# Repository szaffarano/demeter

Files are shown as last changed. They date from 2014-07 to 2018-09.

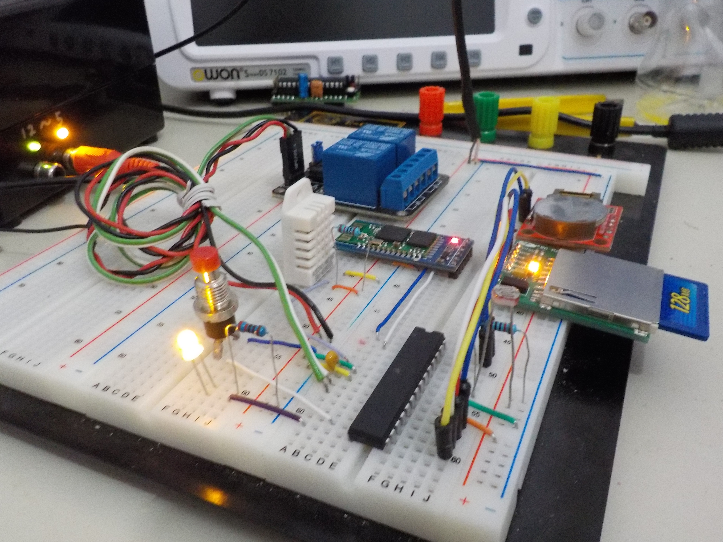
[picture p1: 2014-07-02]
photos/prototipo.JPG

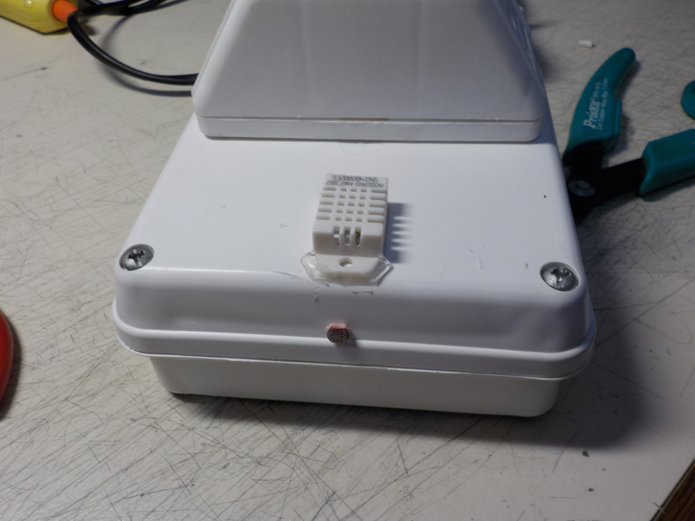
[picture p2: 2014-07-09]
photos/terminado2.JPG

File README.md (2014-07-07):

## Demeter

Controlador de riego que incorpora algunas mejoras con respecto a su predecesor baudino relacionadas con el manejo remoto y ampliación de sensores que maneja.

Está implementado en un microcontrolador AVR ATMega328 **sin bootloeader ni librerías Arduino**.

Versión preliminar con una implementación parcial del protocolo modbus.

### Roadmap

- ~~Terminar de mapear registros modbus a sensores, parámetros y comandos del controlador.~~
- Implementar servicio rest para interactuar remotamente.
- Realizar prueba de concepto para usar NRF24L01+ en lugar del módulo bluetooth.
- ~~Documentar esquemáticos en kicad~~.
- Armar una webapp para administrar el controlador.
- Incorporar interrupción watchdog para preveer posibles fallos.
- Implementar los relays usando triacs+opto.
- Agregar sensor de humedad de tierra.
- Desdoblar los controles para riego tradicional (tierra) e hidropónico en forma independiente.
- Optimizar lógica en los mapeos para ahorrarse algunos ciclos de cpu y memoria.
- Agregar en el cliente python funciones de alto nivel (ej get_date que lea grupo de registros de la fecha en vez de llamar a read_holding_registers).
- ~~Refactorizar mapeo de registros modbus para optimizar bits y que no quede todo en uint16_t.~~ (DUPLICADO).
- Optimizar algoritmo en los callbacks modbus.
- Generar tickets github para no mantener un archivo de pendientes...

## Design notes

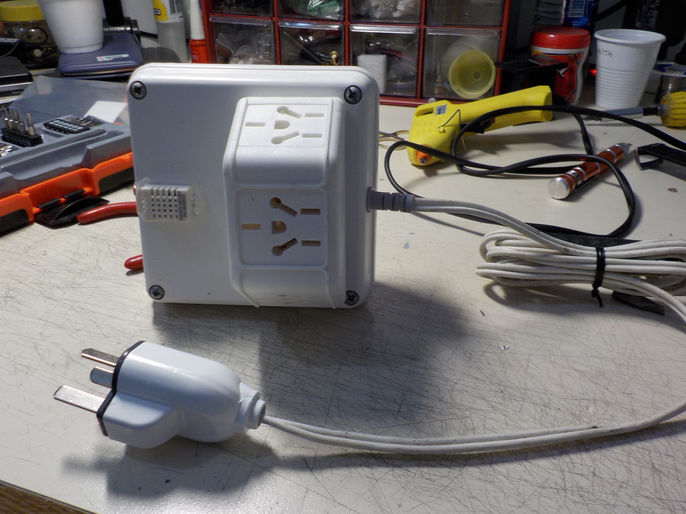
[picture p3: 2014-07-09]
photos/terminado1.JPG

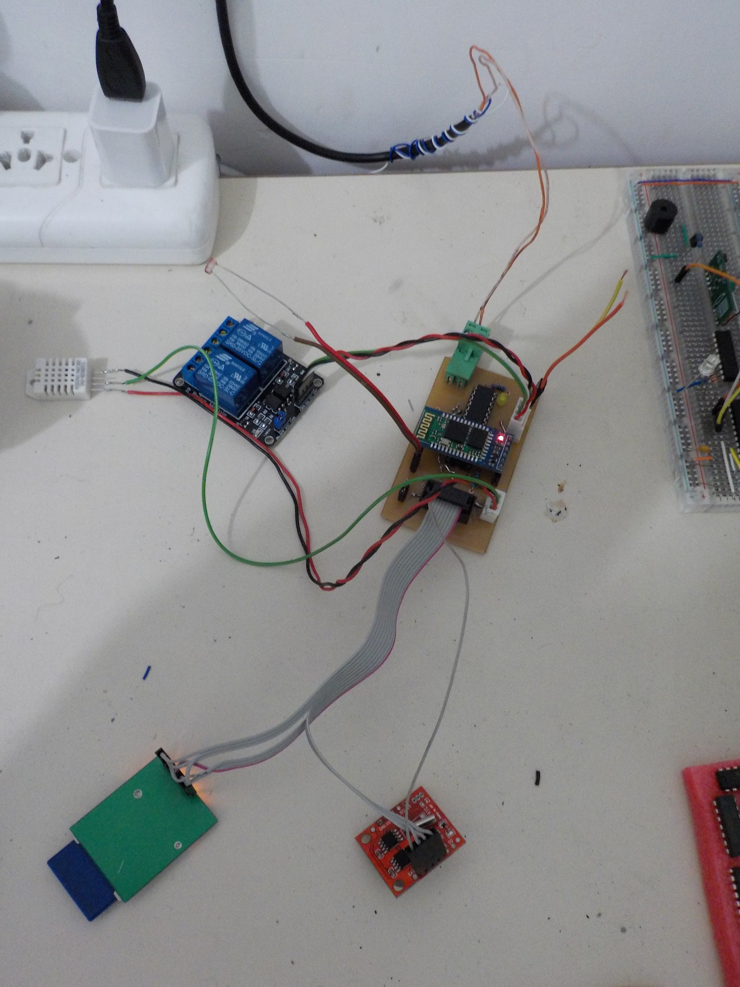
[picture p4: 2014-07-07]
photos/pcb_comienzo.JPG

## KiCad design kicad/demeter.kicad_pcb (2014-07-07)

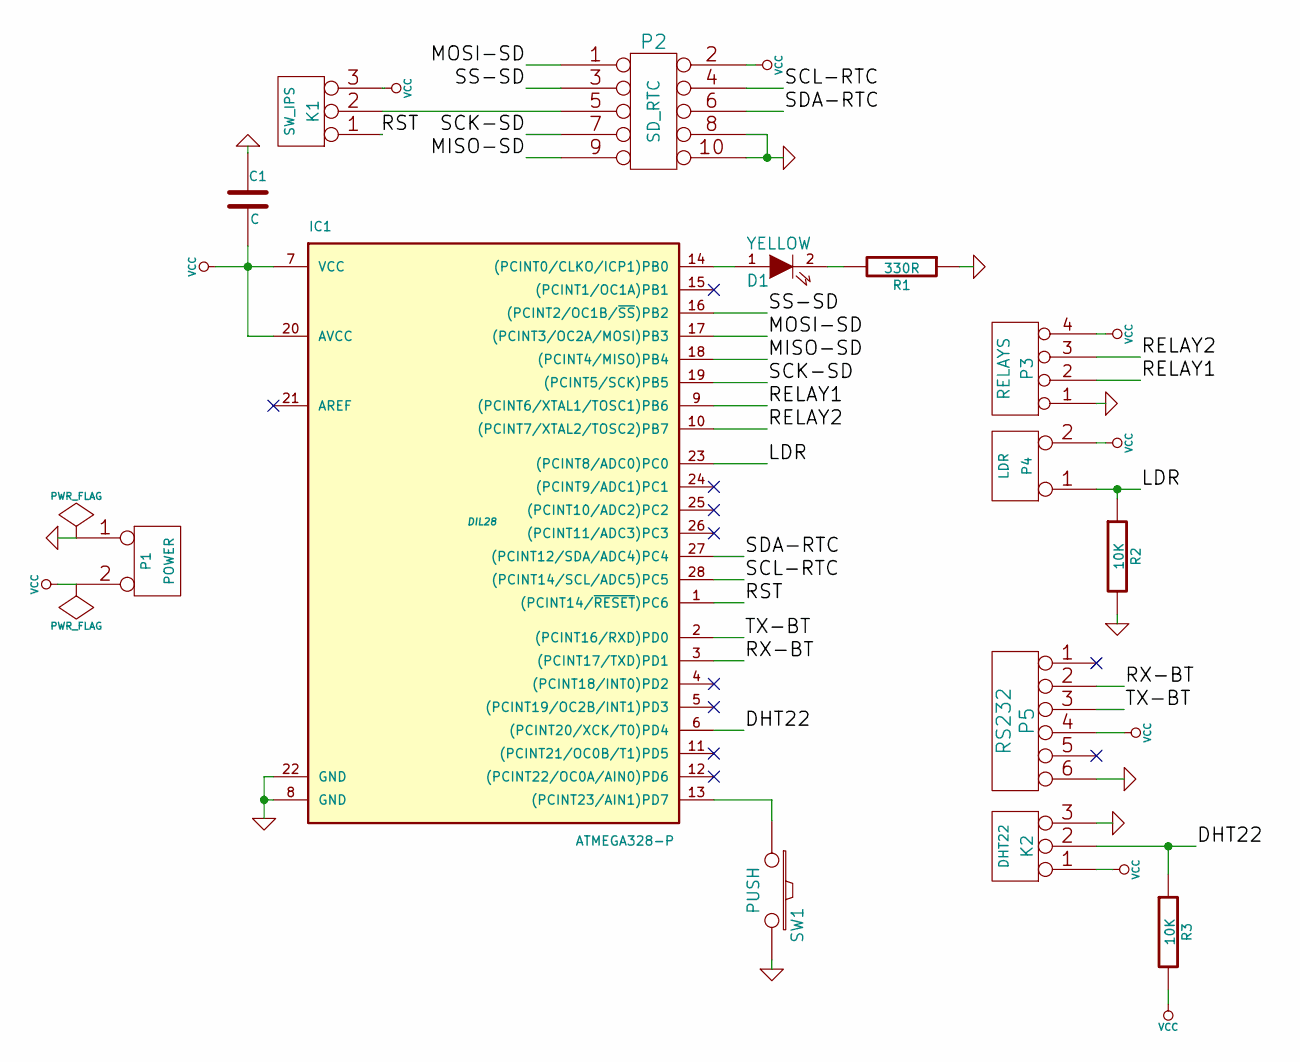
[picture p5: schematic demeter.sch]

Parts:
C1: C
D1: YELLOW
IC1: ATMEGA328-P; DIL28
K1: SW_IPS
K2: DHT22
P1: POWER
P2: SD_RTC
P3: RELAYS
P4: LDR
P5: RS232
R1: 330R
R2, R3: 10K
SW1: PUSH

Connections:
/DHT22: IC1.6 ((PCINT20/XCK/T0)PD4), K2.2 (PM), R3.1
/LDR: IC1.23 ((PCINT8/ADC0)PC0), P4.1, R2.1
/MISO-SD: IC1.18 ((PCINT4/MISO)PB4), P2.9
/MOSI-SD: IC1.17 ((PCINT3/OC2A/MOSI)PB3), P2.1
/RELAY1: IC1.9 ((PCINT6/XTAL1/TOSC1)PB6), P3.2
/RELAY2: IC1.10 ((PCINT7/XTAL2/TOSC2)PB7), P3.3
/RST: IC1.1 ((PCINT14/~RESET~)PC6), K1.1
/RX-BT: IC1.3 ((PCINT17/TXD)PD1), P5.2
/SCK-SD: IC1.19 ((PCINT5/SCK)PB5), P2.7
/SCL-RTC: IC1.28 ((PCINT14/SCL/ADC5)PC5), P2.4
/SDA-RTC: IC1.27 ((PCINT12/SDA/ADC4)PC4), P2.6
/SS-SD: IC1.16 ((PCINT2/OC1B/~SS~)PB2), P2.3
/TX-BT: IC1.2 ((PCINT16/RXD)PD0), P5.3
GND: C1.1, IC1.8 (GND), IC1.22 (GND), K2.3, P1.1, P2.8, P2.10, P3.1, P5.6, R1.1, R2.2, SW1.2
unnamed: D1.1 (A), IC1.14 ((PCINT0/CLKO/ICP1)PB0)
unnamed: D1.2 (K), R1.2
unnamed: IC1.13 ((PCINT23/AIN1)PD7), SW1.1
unnamed: K1.2 (PM), P2.5
VCC: C1.2, IC1.7 (VCC), IC1.20 (AVCC), K1.3, K2.1, P1.2 (PM), P2.2, P3.4, P4.2 (PM), P5.4, R3.2

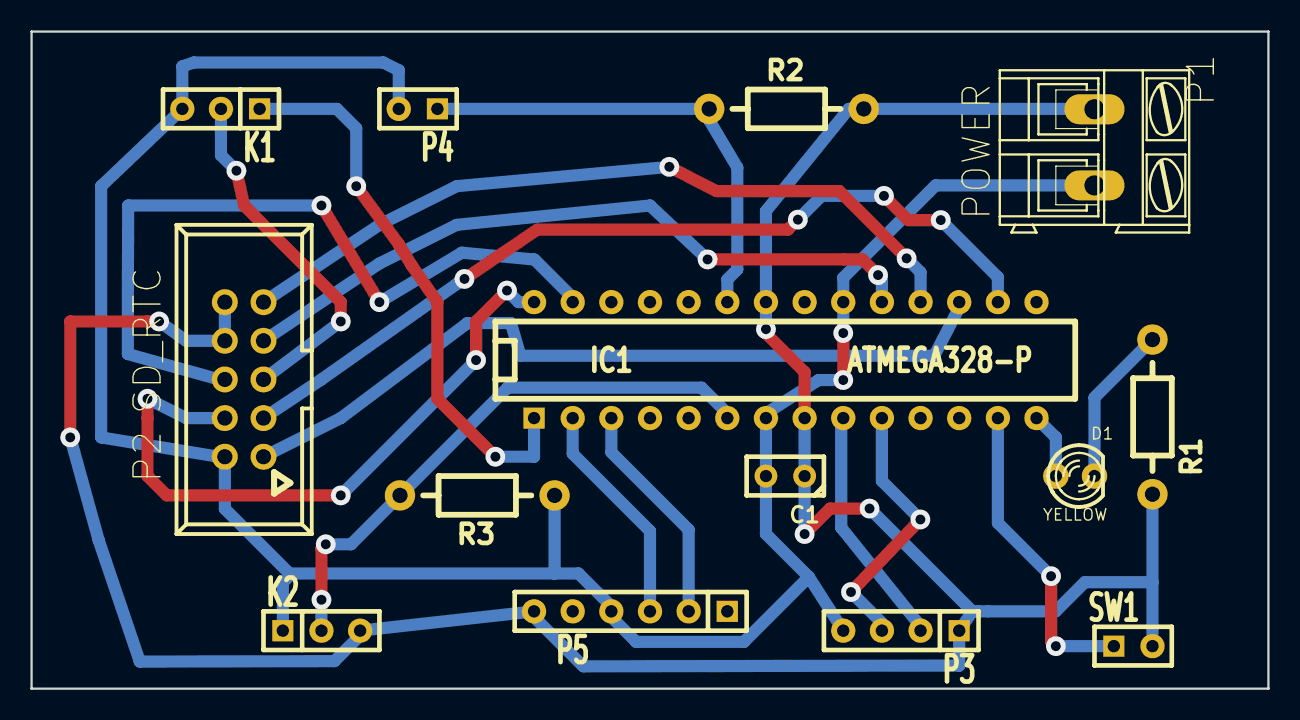
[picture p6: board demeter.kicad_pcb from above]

Board: 2 copper layers, 81.3 x 43.2 mm, 14 parts (0 on the bottom side), 19 nets.

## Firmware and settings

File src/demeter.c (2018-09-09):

/*
 * main.c
 *
 *  Created on: 07/06/2014
 *      Author: sebas
 */

#include <mb.h>
#include <mbport.h>

#include <avr/io.h>
#include <util/delay.h>
#include <avr/interrupt.h>
#include <string.h>
#include <stdlib.h>
#include <ctype.h>

#include <demeter.h>
#include <adc.h>
#include <ports.h>
#include <timer.h>

#include <config.h>

#include <DHT22.h>

#include <stdio.h>

#include <ff.h>

#include <i2c.h>
#include <rtc.h>
#include <rtc_ds1307.h>

#define DATETIME_SIZE	(sizeof(datetime_t) / 2)
#define EVENTS_SIZE		((sizeof(event_t) * MAX_EVENTS) / 2)
#define LOGEVENT_SIZE	(sizeof(uint16_t) / 2)
#define STATE_SIZE		(sizeof(state_t) / 2)
#define NUMBER_OF_COILS	2

FATFS fs;
FIL log_file;
rtc_device_t *rtc = &rtc_ds1307;

state_t state;
datetime_t datetime;
uint8_t relays; /* estado de los relays, lo manejo con bitwise operations */

// "yyyymmdd.log"
static char log_filename[13] = "nn.log";
static char last_logfilename[13] = "empty.log";

volatile unsigned int ticks = 0;

static void timer0_callback(void);
static inline long get_seconds(instant_t t);
static inline void update_state(void);
static inline void update_log_filename(void);

/**
 * MCU: Atmega328
 * Fuses: Oscilador interno a 8 Mhz (sin dividir por 8)
 * 		-U lfuse:w:0xe2:m -U hfuse:w:0xd1:m -U efuse:w:0x07:m
 */
int main(void) {
	adc_init();

	timer0_init(timer0_callback);

	i2c_init();

	rtc_init(rtc);
	rtc_sqw_rate(rtc, 1);
	rtc_sqw_enable(rtc);
	rtc_clock_start(rtc);

	eMBInit(MB_RTU, 0x03, 0, 9600, MB_PAR_NONE);
	eMBSetSlaveID(0x3, TRUE, (UCHAR*) "demeter", 8);
	eMBEnable();

	blinkenlight(5, 100);

	parameters_init();

	ports_init();

	f_mount(&fs, "", 0);
	update_log_filename();

	while (1) {
		eMBPoll();
		update_state();

		_delay_ms(100);
	}

	return (0);
}

static inline void update_state(void) {
	DHT22_DATA_t sensor_values;
	rtc_datetime_24h_t current_dt;
	readDHT22(&sensor_values);
	rtc_read(rtc, &current_dt);

	event_t* events = get_events();
	long start_secs;
	long current_secs;
	uint8_t i = 0;
	uint8_t flag = 0;

	state.temperature = sensor_values.raw_temperature;
	state.humidity = sensor_values.raw_humidity;
	state.light = adc_read(PHOTORESISTOR);

	datetime = (datetime_t ) { .year = current_dt.year, .month =
					current_dt.month, .date = current_dt.date, .hour =
					current_dt.hour, .minute = current_dt.minute, .second =
					current_dt.second };

	current_secs = get_seconds((instant_t ) {
					datetime.hour,
					datetime.minute,
					datetime.second });

	// recorro eventos para ver si tengo que activar relays
	for (i = 0; i < MAX_EVENTS; i++) {
		if (events[i].enabled) {
			start_secs = get_seconds(events[i].start);
			if (start_secs < current_secs
					&& (start_secs + events[i].duration) > current_secs) {
				flag |= (1 << events[i].target); /* activar el evento */
			}
		}
	}

	// si activaron coil, estamos dentro de un evento o presionaron pulsador
	for (uint8_t i = 0; i < NUMBER_OF_COILS; i++) {
		if (relays & (1 << i) || (flag & (1 << i)) || is_pushed()) {
			enable_relay(i);
		} else {
			disable_relay(i);
		}
	}

	if (ticks >= get_log_interval()) {
		update_log_filename(); /* si cambio el dia y hay que hacer roll del archivo */

		//yyyyMMddhhmmss	light	humidity	temperature
		f_printf(&log_file, "%04d%02d%02d%02d%02d%02d\t%d\t%d\t%d\t%d\t%d\n",
				datetime.year, datetime.month, datetime.date, datetime.hour,
				datetime.minute, datetime.second, state.light, state.humidity,
				state.temperature, is_relay_enabled(0), is_relay_enabled(1));
		f_sync(&log_file);
		ticks = 0;
	}
}

void timer0_callback() {
	ticks++;
	LED_PORT ^= _BV(LED);
}

/* Callbacks Modbus */

eMBErrorCode eMBRegInputCB(UCHAR * pucRegBuffer, USHORT usAddress,
		USHORT usNRegs) {

	if ((usAddress + usNRegs - 1) > STATE_SIZE) {
		return MB_ENOREG;
	}
	int16_t* raw_state = (int16_t*) &state;

	raw_state += usAddress - 1;
	while (usNRegs > 0) {
		*pucRegBuffer++ = (*raw_state >> 8);
		*pucRegBuffer++ = (*raw_state & 0xFF);
		usNRegs--;
		raw_state++;
	}

	return MB_ENOERR;
}

/**
 * Holding registers (empieza en 1):
 * 	LOG_INTERVAL + DATETIME + EVENTS
 */
eMBErrorCode eMBRegHoldingCB(UCHAR * buffer, USHORT address, USHORT regs,
		eMBRegisterMode mode) {

	// indice para saber por qué grupo de registros voy avanzando
	uint16_t idx = address;

	// hago operaciones de bit en una variable, para no usar dos
	// es para indicar si debo actualizar el grupo de registros
	// de eventos y/o datetime.
	uint8_t flag = 0;

	// grupo de registros correspondiente a datetime
	uint16_t* dt = (uint16_t*) &datetime;

	// grupo de registros correspondiente a los eventos.
	uint16_t* events = (uint16_t*) get_events();

	if ((address + regs - 1) > (EVENTS_SIZE + LOGEVENT_SIZE + DATETIME_SIZE)) {
		return MB_ENOREG;
	}

	// si me piden algo que va mas allá de logevent (primer registro)
	// avanzo el siguiente grupo, datetime
	if (address > LOGEVENT_SIZE) {
		dt += address - LOGEVENT_SIZE - 1;
	}

	// si me piden algo que va mas allá del segundo registro (datetime)
	// avanzo el tercer grupo, events hasta donde haga falta.
	if (address > (LOGEVENT_SIZE + DATETIME_SIZE)) {
		events += address - LOGEVENT_SIZE - DATETIME_SIZE - 1;
	}

	// operación de lectura
	if (mode == MB_REG_READ) {
		for (; idx < regs + address; idx++) {
			if (idx > 0 && idx <= LOGEVENT_SIZE) {
				uint16_t log_interval = get_log_interval();
				*buffer++ = (log_interval >> 8);
				*buffer++ = (log_interval & 0xFF);
			} else if (idx > LOGEVENT_SIZE
					&& idx <= (LOGEVENT_SIZE + DATETIME_SIZE)) {
				*buffer++ = (*dt >> 8);
				*buffer++ = (*dt & 0xFF);
				dt++;
			} else {
				*buffer++ = (*events >> 8);
				*buffer++ = (*events & 0xFF);
				events++;
			}
		}
		// operación de escritura
	} else {
		for (; idx < regs + address; idx++) {
			if (idx > 0 && idx <= LOGEVENT_SIZE) {
				uint16_t log_interval = (*buffer++ << 8);
				log_interval |= (*buffer++ & 0xFF);
				set_log_interval(log_interval);
			} else if (idx > LOGEVENT_SIZE
					&& idx <= (LOGEVENT_SIZE + DATETIME_SIZE)) {
				*dt = (*buffer++ << 8);
				*dt |= (*buffer++ & 0xFF);
				dt++;
				flag |= (1 << 1); /* se modifica algun campo de la fecha, marco flag */
			} else {
				*events = (*buffer++ << 8);
				*events |= (*buffer++ & 0xFF);
				events++;
				flag |= (1 << 2); /* se modifica algún evento, marco flag */
			}
		}

		if ((flag & (1 << 1))) {
			rtc_datetime_24h_t newdate;
			newdate.year = datetime.year;
			newdate.month = datetime.month;
			newdate.date = datetime.date;
			newdate.hour = datetime.hour;
			newdate.minute = datetime.minute;
			newdate.second = datetime.second;
			rtc_write(rtc, &newdate);
		}

		if ((flag & (1 << 2))) {
			set_events(get_events());
		}
	}

	return MB_ENOERR;
}

eMBErrorCode eMBRegCoilsCB(UCHAR * pucRegBuffer, USHORT usAddress,
		USHORT usNCoils, eMBRegisterMode eMode) {
	if (usAddress + usNCoils - 1 > NUMBER_OF_COILS) {
		return MB_ENOREG;
	}
	usAddress--; /* empiezo en cero. */
	if (eMode == MB_REG_READ) {
		while (usNCoils > 0) {
			if (relays & (1 << usAddress)) {
				*pucRegBuffer |= (1 << usAddress);
			}
			usNCoils--;
			usAddress++;
		}
	} else {
		*pucRegBuffer <<= usAddress;
		while (usNCoils > 0) {
			if ((*pucRegBuffer & (1 << usAddress))) {
				relays |= (1 << usAddress);
			} else {
				relays &= ~(1 << usAddress);
			}
			usNCoils--;
			usAddress++;
		}
	}
	return MB_ENOERR;
}

eMBErrorCode eMBRegDiscreteCB(UCHAR * pucRegBuffer, USHORT usAddress,
		USHORT usNDiscrete) {
	return MB_ENOREG;
}

/**
 * Función usada para setearle la fecha a los archivos.
 */
DWORD get_fattime(void) {
	rtc_datetime_24h_t current_dt;
	rtc_read(rtc, &current_dt);
	return ((DWORD) (current_dt.year - 1980) << 25) /* Year */
	| ((DWORD) current_dt.month << 21) /* Month */
	| ((DWORD) current_dt.date << 16) /* Mday */
	| ((DWORD) current_dt.hour << 11) /* Hour */
	| ((DWORD) current_dt.minute << 5) /* Min */
	| ((DWORD) current_dt.second >> 1); /* Sec */
}

/**
 * Convierte un instant_t a segundos.  Esos segundos representan el tiempo
 * transcurrido desde las 0 hs hasta el momento del instante
 * propiamente dicho.
 */
static inline long get_seconds(instant_t t) {
	return (t.hour * 60 * 60) + (t.minute * 60) + t.second;
}

static inline void update_log_filename(void) {
	rtc_datetime_24h_t dt;
	rtc_read(rtc, &dt);
	sprintf(log_filename, "%04d%02d%02d.log", dt.year, dt.month, dt.date);
	if (strcmp(log_filename, last_logfilename) != 0) {
		f_close(&log_file);
		if (f_open(&log_file, log_filename, FA_OPEN_ALWAYS | FA_WRITE)
				== FR_OK) {
			if (f_lseek(&log_file, f_size(&log_file)) == FR_OK) {
				f_sync(&log_file);
			}
		}
		strcpy(last_logfilename, log_filename);
	}
}

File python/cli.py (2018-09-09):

#!/usr/bin/env python
# -*- coding: utf-8 -*-

import logging
import argparse

from utils import Console, DemeterClient
from pymodbus.pdu import ExceptionResponse
from pymodbus.register_write_message import WriteMultipleRegistersResponse
from pymodbus.register_read_message import ReadRegistersResponseBase
from pymodbus.bit_read_message import ReadBitsResponseBase
from pymodbus.bit_write_message import WriteMultipleCoilsResponse

LOG_FILENAME = '/tmp/modbus-cli.log'
HISTORY_FILENAME = '/tmp/.modbus_history'

MODBUS_CLIENT_ID = 0x03

# Configuración del log
logging.basicConfig(
    filename=LOG_FILENAME,
    level=logging.DEBUG,
)

# Opciones para el autocompletado
autocompletions = {
    'read_coils': [],
    'read_discrete_inputs': [],
    'read_holding_registers': [],
    'read_input_registers': [],
    'write_coils': [],
    'write_registers': [],

    'get_datetime': [],
    'set_datetime': [],
    'get_loginterval': [],
    'set_loginterval': [],
    'read_event': [],
    'write_event': [],
    'read_events': [],
    'disable_event': [],
    'enable_event': [],
    'disable_relay': [],
    'enable_relay': [],
    'temperature': [],
    'humidity': [],
    'light': [],
}


def __configure_args():
    parser = argparse.ArgumentParser()

    parser.add_argument("-d", "--device",
                        help="Path to the bluetooth device to use",
                        default="/dev/rfcomm1")

    parser.add_argument("-m", "--method",
                        help="Connection method",
                        default="rtu")

    parser.add_argument("-s", "--stop",
                        help="Stop bits",
                        default=2)

    parser.add_argument("-S", "--size",
                        help="Byte size",
                        default=8)

    parser.add_argument("-p", "--parity",
                        help="If it use parity",
                        default="N")

    parser.add_argument("-b", "--bauds",
                        help="Baud rate",
                        default=9600)

    parser.add_argument("-t", "--timeout",
                        help="Timeout",
                        default=1)
    return parser


if __name__ == '__main__':
    parser = __configure_args()
    args = parser.parse_args()

    # Configuración de Modbus
    modbus_config = {
        'method': args.method,
        'port': args.device,
        'stopbits': int(args.stop),
        'bytesize': int(args.size),
        'parity': args.parity,
        'baudrate': int(args.bauds),
        'timeout': int(args.timeout)
    }

    demeter = DemeterClient(MODBUS_CLIENT_ID, modbus_config)
    console = Console(autocompletions, HISTORY_FILENAME)

    while True:
        cli = console.input('modbus> ')

        command = cli[0]
        arguments = cli[1:] if len(cli) > 1 else []

        if not demeter.is_valid(command):
            print("%s: unknown command." % command)
            continue

        response = demeter.execute(command, arguments)
        if response is None:
            print("empty response")
        elif isinstance(response, ExceptionResponse):
            print("Execution error: %s" % response)
        else:
            if isinstance(response, WriteMultipleRegistersResponse):
                print("%s registers have been written" % response.count)
            elif isinstance(response, ReadRegistersResponseBase):
                print("%s registers have been read: %s" %
                      (len(response.registers), response.registers))
            elif isinstance(response, ReadBitsResponseBase):
                print("%s coils have been read: %s" %
                      (len(response.bits), response.bits))
            elif isinstance(response, WriteMultipleCoilsResponse):
                print("%s coils have been written" % response.count)
            else:
                print(response)

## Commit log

2014-06-07 Agrega macro para simplificar código. Renombra variables para claridad de funcionalidad
2014-06-07 Refactoring de nombres y mueve de lugar macros de uso interno
2014-06-08 Incorpora librería para interactuar con sensor DHT22
2014-06-08 Incorpora librería para señales analógicas (sensor lumínico)
2014-06-08 Incorpora librería RTC y dependencía i2c.
2014-06-08 Incorpora librería para manipulación de ports de I/O
2014-06-08 Incorpora librería de temporizadores
2014-06-08 Modificaciones para adaptar a las nuevas librerías.
2014-06-08 Agrego impresión en usart para indicar que se escribe en el log
2014-06-08 Modifica prescaler para oscilador de 8Mhz en lugar del externo de 16 Mhz que se estaba usando
2014-06-12 Agrega import que hacia falta
2014-06-12 Agrega métodos para manejar relays
2014-06-12 Incorporo makefile para agilizar construcción
2014-06-12 Incorpora menu muy simple para interactuar con la configuración
2014-06-28 Adapta puertos para utilizar sd en datalogger. Necesario por el temporizador de la libreria ff que se solapaba con temporizador para monitoreo de eventos
2014-06-28 Se pasa a usar temporizador 0, de 8 bits, pues el 1 lo necesita la libreria ff
2014-06-28 Incorpora cliente python para interactuar con modbus
2014-06-28 Mejora en el manejo de configuraciones en eeprom.
2014-06-28 Cambia flag de gcc para omitir warning por libreria ff
2014-06-28 Adapta todo lo hecho con una implementacion muy simple de modbus, resta mejorar el mapeo de registros
2014-06-28 Configuraciones de git
2014-06-28 Eliminacion de libreria que no se usa
2014-06-28 Algo de info
2014-06-30 Arregla bug con los puertos ya que cuando se redefinieró el port del pulsador quedó desactualizada la inicialización del pin change interrput correspondiente. Agrega funcionalidad al cliente python. 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
    [cli.py, demeter.c, utils.py]
2014-07-01 Renombra constantes de delays para comenzar en cero. Cambia semántica de activación de relays para tomar cero como primer relay en vez de uno. Agrega método para informar si presionaron el pulsador (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
2014-07-01 Mejora lógica de manejo de relays.
2014-07-01 Arregla bug en write_coils, cuando se escribía desde una posición mayor a cero.
    [demeter.c]
2014-07-01 Implementa comandos de alto nivel para interactuar con todos los sensores y registros
2014-07-02 Agrega manejo de errores en comandos.
    [utils.py]
2014-07-02 Mejora formato del log para no loguear boludeces. Incorpora file rolling para evitar que los archivos crezcan indefinidamente (rolea por dia)
2014-07-03 Esquemático y netlis
    [demeter.sch]
2014-07-03 Agrega archivo de footprints.
2014-07-07 Archivos del pcb
    [demeter-B_Cu.gbl, demeter-Edge_Cuts.gbr, demeter-F_Cu.gtl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]
2014-07-07 Esquemáticos Kicad
    [demeter.dsn, demeter.kicad_pcb, demeter.sch]
2014-07-07 Excluye archivos temporales de kicad
2014-07-07 Fixea bug en validación de parámetros
    [utils.py]
2014-07-07 Agrega foto con primera aproximación al prototipo en pcb
2014-07-09 Agrega comandos de alto nivel para habilitar/deshabilitar eventos, informar temperatura, humedad y nivel lumínico.
2014-07-09 Agrega en el log información sobre el estado de los relays.
